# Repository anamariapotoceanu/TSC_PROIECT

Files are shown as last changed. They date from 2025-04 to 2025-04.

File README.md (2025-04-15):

# OpenBook E-Reader

OpenBook este un e-reader open-source construit in jurul microcontrollerului ESP32-C6-WROOM-1. Dispozitivul ofera o experienta de lectura cu afisaj e-paper, butoane fizice, conectivitate wireless si senzori de mediu integrati.

## DIAGRAMA BLOC
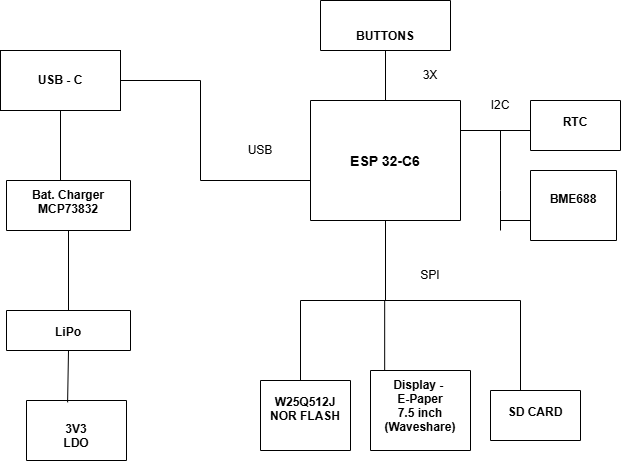
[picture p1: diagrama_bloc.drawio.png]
Diagrama Bloc


## BOM

| DENUMIRE | SITE ACHIZITIONARE | DATASHEET |
|---|---|---|
| BOOT_BUTON | [LINK](https://www.snapeda.com/parts/EVQP7L01P/Panasonic%20Electronic%20Components/view-part/?welcome=home) | [LINK](https://www.snapeda.com/parts/EVQP7L01P/Panasonic/datasheet/) |
| C1 - C10 | [LINK](https://componentsearchengine.com/part-view/CC0402MRX5R5BB106/YAGEO) | [LINK](https://componentsearchengine.com/Datasheets/2/CC0402MRX5R5BB106.pdf) |
| C1_BAT | [LINK](https://componentsearchengine.com/part-view/CC0402MRX5R5BB106/YAGEO) | [LINK](https://componentsearchengine.com/Datasheets/2/CC0402MRX5R5BB106.pdf) |
| C1_BAT2 | [LINK](https://componentsearchengine.com/part-view/CC0402MRX5R5BB106/YAGEO) | [LINK](https://componentsearchengine.com/Datasheets/2/CC0402MRX5R5BB106.pdf) |
| C2_BAT | [LINK](https://componentsearchengine.com/part-view/CC0402MRX5R5BB106/YAGEO) | [LINK](https://componentsearchengine.com/Datasheets/2/CC0402MRX5R5BB106.pdf) |
| C4_USB | [LINK](https://componentsearchengine.com/part-view/CC0402MRX5R5BB106/YAGEO) | [LINK](https://componentsearchengine.com/Datasheets/2/CC0402MRX5R5BB106.pdf) |
| C5_USB | [LINK](https://componentsearchengine.com/part-view/CC0402MRX5R5BB106/YAGEO) | [LINK](https://componentsearchengine.com/Datasheets/2/CC0402MRX5R5BB106.pdf) |
| C10_SUPERCAR | [LINK](https://industry.panasonic.com/global/en/products/control/switch/light-touch/number/evqpuj02k) | [LINK](https://industry.panasonic.com/global/en/downloads?tab=catalog&small_g_cd=203&part_no=EVQPUJ02K) |
| CHANGE_BUTTON | [LINK](https://www.snapeda.com/parts/EVQP7L01P/Panasonic%20Electronic%20Components/view-part/?welcome=home) | [LINK](https://www.snapeda.com/parts/EVQP7L01P/Panasonic/datasheet/) |
| CHG_LED | [LINK](https://www.snapeda.com/parts/KP-1608SURCK/Kingbright/view-part/?ref=search&t=LED%200603) | [LINK](https://www.snapeda.com/parts/KP-1608SURCK/Kingbright/datasheet/) |
| C_DELAY | [LINK](https://componentsearchengine.com/part-view/CC0402MRX5R5BB106/YAGEO) | [LINK](https://componentsearchengine.com/Datasheets/2/CC0402MRX5R5BB106.pdf) |
| D1 | [LINK](https://www.snapeda.com/parts/USBLC6-2SC6Y/STMicroelectronics/view-part/?ref=eda) | [LINK](https://www.snapeda.com/parts/USBLC6-2SC6Y/STMicroelectronics/view-part/?ref=eda) |
| D2 | [LINK](https://ro.mouser.com/ProductDetail/KYOCERA-AVX/SD0805S020S1R0?qs=jCA%252BPfw4LHbpkAoSnwrdjw%3D%3D) | [LINK](https://ro.mouser.com/datasheet/2/40/schottky-3165252.pdf) |
| D3 | [LINK](https://ro.mouser.com/ProductDetail/KYOCERA-AVX/SD0805S020S1R0?qs=jCA%252BPfw4LHbpkAoSnwrdjw%3D%3D) | [LINK](https://ro.mouser.com/datasheet/2/40/schottky-3165252.pdf) |
| D4 | [LINK](https://ro.mouser.com/ProductDetail/KYOCERA-AVX/SD0805S020S1R0?qs=jCA%252BPfw4LHbpkAoSnwrdjw%3D%3D) | [LINK](https://ro.mouser.com/datasheet/2/40/schottky-3165252.pdf) |
| D5 | [LINK](https://ro.mouser.com/ProductDetail/KYOCERA-AVX/SD0805S020S1R0?qs=jCA%252BPfw4LHbpkAoSnwrdjw%3D%3D) | [LINK](https://ro.mouser.com/datasheet/2/40/schottky-3165252.pdf) |
| D6 | [LINK](https://www.snapeda.com/parts/PGB1010603MR/Littelfuse/view-part/?ref=eda) | [LINK](https://www.snapeda.com/parts/PGB1010603MR/Littelfuse%20Inc./datasheet/) |
| D7 | [LINK](https://ro.mouser.com/ProductDetail/KYOCERA-AVX/SD0805S020S1R0?qs=jCA%252BPfw4LHbpkAoSnwrdjw%3D%3D) | [LINK](https://ro.mouser.com/datasheet/2/40/schottky-3165252.pdf) |
| D8 | [LINK](https://www.snapeda.com/parts/PGB1010603MR/Littelfuse/view-part/?ref=eda) | [LINK](https://www.snapeda.com/parts/PGB1010603MR/Littelfuse%20Inc./datasheet/) |
| D9 | [LINK](https://www.snapeda.com/parts/PGB1010603MR/Littelfuse/view-part/?ref=eda) | [LINK](https://www.snapeda.com/parts/PGB1010603MR/Littelfuse%20Inc./datasheet/) |
| D10 | [LINK](https://www.snapeda.com/parts/PGB1010603MR/Littelfuse/view-part/?ref=eda) | [LINK](https://www.snapeda.com/parts/PGB1010603MR/Littelfuse%20Inc./datasheet/) |
| D11 | [LINK](https://www.snapeda.com/parts/PGB1010603MR/Littelfuse/view-part/?ref=eda) | [LINK](https://www.snapeda.com/parts/PGB1010603MR/Littelfuse%20Inc./datasheet/) |
| D12 | [LINK](https://www.snapeda.com/parts/PGB1010603MR/Littelfuse/view-part/?ref=eda) | [LINK](https://www.snapeda.com/parts/PGB1010603MR/Littelfuse%20Inc./datasheet/) |
| EPD_C1 - EPD_C12 | [LINK](https://componentsearchengine.com/part-view/CC0402MRX5R5BB106/YAGEO) | [LINK](https://componentsearchengine.com/Datasheets/2/CC0402MRX5R5BB106.pdf) |
| IC1 | [LINK](https://componentsearchengine.com/part-view/BD5229G-TR/ROHM%20Semiconductor) | [LINK](https://datasheet.datasheetarchive.com/originals/distributors/Datasheets_SAMA/f2b9741ef86007909f138d561a359946.pdf) |
| IC4 | [LINK](https://componentsearchengine.com/part-view/XC6220A331MR-G/Torex) | [LINK](https://product.torexsemi.com/system/files/series/xc6220.pdf) |
| J1 | [LINK](https://componentsearchengine.com/part-view/FH34SRJ-24S-0.5SH(99)/Hirose) | [LINK](https://www.hirose.com/en/product/document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) |
| J2 | [LINK](https://componentsearchengine.com/part-view/USB4110-GF-A/GCT%20(GLOBAL%20CONNECTOR%20TECHNOLOGY)) | [LINK](https://gct.co/files/drawings/usb4110.pdf) |
| J3 | [LINK](https://www.snapeda.com/parts/PRT-14417/SparkFun/view-part/) | [LINK](https://www.snapeda.com/parts/PRT-14417/SparkFun%20Electronics/datasheet/) |
| J4 | [LINK](https://www.snapeda.com/parts/112A-TAAR-R03/Attend/view-part/) | [LINK](https://www.snapeda.com/parts/112A-TAAR-R03/Attend/datasheet/) |
| MCP73831 | [LINK](https://ro.mouser.com/ProductDetail/Microchip-Technology/MCP73831T-2ACI-OT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) | [LINK](https://ro.mouser.com/datasheet/2/268/MCP73831_Family_Data_Sheet_DS20001984H-3441711.pdf) |
| L1 | [LINK](https://ro.mouser.com/ProductDetail/Wurth-Elektronik/744043680?qs=PGXP4M47uW6VkZq%252BkzjrHA%3D%3D) | [LINK](https://www.we-online.com/components/products/datasheet/744043680.pdf) |
| PFMF.050.1 | [LINK](https://ro.mouser.com/ProductDetail/EPCOS-TDK/B72520T0350K062?qs=dEfas%2FXlABIszF52uu7vrg%3D%3D) | [LINK](https://www.tdk-electronics.tdk.com/inf/75/db/CTVS_14/Surge_protection_series.pdf) |
| Q1 | [LINK](https://componentsearchengine.com/part-view/DMG2305UX-7/Diodes%20Incorporated) | [LINK](https://www.diodes.com//assets/Datasheets/DMG2305UX.pdf) |
| Q2 | [LINK](https://componentsearchengine.com/part-view/DMG2305UX-7/Diodes%20Incorporated) | [LINK](https://www.diodes.com//assets/Datasheets/DMG2305UX.pdf) |
| Q3 | [LINK](https://componentsearchengine.com/part-view/SI1308EDL-T1-GE3/Vishay) | [LINK](https://componentsearchengine.com/part-view/SI1308EDL-T1-GE3/Vishay) |
| R1 - R10 | [LINK](https://componentsearchengine.com/part-view/R0402%201%25%20100%20K%20(RC0402FR-07100KL)/YAGEO) | [LINK](https://www.yageo.com/upload/media/product/products/datasheet/rchip/PYu-RC_Group_51_RoHS_L_12.pdf) |
| R1_PINH | [LINK](https://componentsearchengine.com/part-view/R0402%201%25%20100%20K%20(RC0402FR-07100KL)/YAGEO) | [LINK](https://www.yageo.com/upload/media/product/products/datasheet/rchip/PYu-RC_Group_51_RoHS_L_12.pdf) |
| R1_PINH1 | [LINK](https://componentsearchengine.com/part-view/R0402%201%25%20100%20K%20(RC0402FR-07100KL)/YAGEO) | [LINK](https://www.yageo.com/upload/media/product/products/datasheet/rchip/PYu-RC_Group_51_RoHS_L_12.pdf) |
| R1_BAT | [LINK](https://componentsearchengine.com/part-view/R0402%201%25%20100%20K%20(RC0402FR-07100KL)/YAGEO) | [LINK](https://www.yageo.com/upload/media/product/products/datasheet/rchip/PYu-RC_Group_51_RoHS_L_12.pdf) |
| R1_PWRUSB | [LINK](https://componentsearchengine.com/part-view/R0402%201%25%20100%20K%20(RC0402FR-07100KL)/YAGEO) | [LINK](https://www.yageo.com/upload/media/product/products/datasheet/rchip/PYu-RC_Group_51_RoHS_L_12.pdf) |
| R2_PINH | [LINK](https://componentsearchengine.com/part-view/R0402%201%25%20100%20K%20(RC0402FR-07100KL)/YAGEO) | [LINK](https://www.yageo.com/upload/media/product/products/datasheet/rchip/PYu-RC_Group_51_RoHS_L_12.pdf) |
| R2-PINH1 | [LINK](https://componentsearchengine.com/part-view/R0402%201%25%20100%20K%20(RC0402FR-07100KL)/YAGEO) | [LINK](https://www.yageo.com/upload/media/product/products/datasheet/rchip/PYu-RC_Group_51_RoHS_L_12.pdf) |
| R2_USB | [LINK](https://componentsearchengine.com/part-view/R0402%201%25%20100%20K%20(RC0402FR-07100KL)/YAGEO) | [LINK](https://www.yageo.com/upload/media/product/products/datasheet/rchip/PYu-RC_Group_51_RoHS_L_12.pdf) |
| R2_USB1 | [LINK](https://componentsearchengine.com/part-view/R0402%201%25%20100%20K%20(RC0402FR-07100KL)/YAGEO) | [LINK](https://www.yageo.com/upload/media/product/products/datasheet/rchip/PYu-RC_Group_51_RoHS_L_12.pdf) |
| RESET_BUTTON | [LINK](https://www.snapeda.com/parts/EVQP7L01P/Panasonic%20Electronic%20Components/view-part/?welcome=home) | [LINK](https://www.snapeda.com/parts/EVQP7L01P/Panasonic/datasheet/) |
| R_BOOT | [LINK](https://componentsearchengine.com/part-view/R0402%201%25%20100%20K%20(RC0402FR-07100KL)/YAGEO) | [LINK](https://www.yageo.com/upload/media/product/products/datasheet/rchip/PYu-RC_Group_51_RoHS_L_12.pdf) |
| R_CAPACITOR | [LINK](https://componentsearchengine.com/part-view/R0402%201%25%20100%20K%20(RC0402FR-07100KL)/YAGEO) | [LINK](https://www.yageo.com/upload/media/product/products/datasheet/rchip/PYu-RC_Group_51_RoHS_L_12.pdf) |
| R_CHANGE | [LINK](https://componentsearchengine.com/part-view/R0402%201%25%20100%20K%20(RC0402FR-07100KL)/YAGEO) | [LINK](https://www.yageo.com/upload/media/product/products/datasheet/rchip/PYu-RC_Group_51_RoHS_L_12.pdf) |
| R_CL1 | [LINK](https://componentsearchengine.com/part-view/R0402%201%25%20100%20K%20(RC0402FR-07100KL)/YAGEO) | [LINK](https://www.yageo.com/upload/media/product/products/datasheet/rchip/PYu-RC_Group_51_RoHS_L_12.pdf) |
| R_RESET | [LINK](https://componentsearchengine.com/part-view/R0402%201%25%20100%20K%20(RC0402FR-07100KL)/YAGEO) | [LINK](https://www.yageo.com/upload/media/product/products/datasheet/rchip/PYu-RC_Group_51_RoHS_L_12.pdf) |
| SENSOR2 | [LINK](https://www.snapeda.com/parts/BME680/Bosch/view-part/?welcome=home) | [LINK](https://www.snapeda.com/parts/BME680/Bosch%20Sensortec/datasheet/) |
| TP | [nan](nan) | [nan](nan) |
| U1 | [LINK](https://www.snapeda.com/parts/W25Q512JVEIQ/Winbond+Electronics/view-part/?ref=eda) | [LINK](https://www.snapeda.com/parts/W25Q512JVEIQ/Winbond+Electronics/view-part/?ref=eda) |
| U2 | [LINK](https://www.snapeda.com/parts/ESP32-C6-WROOM-1-N8/Espressif+Systems/view-part/?ref=eda) | [LINK](https://www.snapeda.com/parts/ESP32-C6-WROOM-1-N8/Espressif%20Systems/datasheet/) |
| U3 | [LINK](https://www.snapeda.com/parts/DS3231SN%23/Analog+Devices/view-part/?ref=eda) | [LINK](https://www.snapeda.com/parts/DS3231SN%23/Analog%20Devices/datasheet/) |
| U4 | [LINK](https://www.snapeda.com/parts/MAX17048G+T10/Analog+Devices/view-part/?ref=eda) | [LINK ](https://www.snapeda.com/parts/MAX17048G+T10/Analog%20Devices/datasheet/) |

## Functionalitate hardware detaliata

OpenBook este un e-reader open-source construit in jurul microcontrollerului ESP32-C6-WROOM-1-N8. Sistemul este modular si a fost gandit pentru consum redus de energie, simplitate si extensibilitate.

### Microcontroller - ESP32-C6-WROOM-1-N8
- Procesor RISC-V 32-bit, frecventa 160 MHz+
- Suport pentru Wi-Fi 6, BLE 5 si USB 2.0 FS
- Interfete disponibile: SPI, I2C, UART, GPIO
- Consum redus: aproximativ 60 mA in activ, sub 100 uA in deep sleep

### Display - E-Paper 7.5 inch (Waveshare)
- Rezolutie 800x480 alb-negru
- Interfata SPI, partajata cu alte periferice
- Foloseste linii dedicate pentru ceas, date, comenzi, reset si status
- Consum doar in timpul refreshului (~30 - 50 mA)

### Senzori de mediu
- **BME688** masoara temperatura, umiditatea, presiunea si calitatea aerului
- Conectat pe magistrala I2C, alaturi de RTC si fuel gauge
- **DS3231**  este un RTC cu backup pe supercapacitor si semnal de intrerupere catre microcontroller
- **MAX17048** (fuel gauge): I2C + ALERT pe IO16
- Un fuel gauge care poate trimite alerta in caz de nivel scazut

### Memorie externa
- W25Q512J, o memorie NOR Flash de 64MB, conectata prin SPI
- Are chip select dedicat pentru acces independent de afisaj

### SD Card (optional)
- Suportat pe aceeasi magistrala SPI cu chip select separat
- Permite extinderea capacitatii de stocare

### Butoane
- Trei butoane tactile conectate direct la pinii microcontrollerului
- Sunt folosite pentru navigare si selectie in interfata
- Gestionate prin intreruperi, cu debounce hardware si software

### Alimentare
- Sistemul este alimentat de o baterie Li-Po de 2500 mAh
- Incarcarea se face prin USB-C cu ajutorul unui MCP73831
- Un semnal digital permite monitorizarea starii de incarcare
- Tensiunea este stabilizata la 3.3V printr-un LDO

### USB-C
- Asigura incarcare si transfer de fisiere in mod MSC (Mass Storage)
- Liniile USB sunt protejate cu diode ESD

### Consum estimativ
- In activ cu Wi-Fi: intre 60 si 100 mA
- In activ fara Wi-Fi: intre 40 si 60 mA
- In standby: aproximativ 10 mA
- In deep sleep: sub 100 uA

### PCB si carcasa
- Placa in 2 straturi, rutare clara pentru alimentare si SPI
- Separare intre zonele digitale si analogice
- Carcasa ABS/PC, usoara si ergonomica

| IO Pin | Semnal | Rol |
|---|---|---|
| EN | RESET  | Semnal de intrare pentru resetare |
| 0| INT_RTC | Semnal de intrerupere generat de modulul RTC |
| 1 | 32KHZ | Oscilator 32kHz pentru RTC |
| 2 | MISO | SPI MISO date de la periferice |
| 3 | EPD_BUSY | Semnal ocupat de la afisaj e-paper |
| 4 | SS_SD | Chip Select pentru SD Card |
| 5 | EPD_DC | Comanda date/controle pentru e-paper |
| 6 | SCK | SPI Clock comun pentru SD, flash si e-paper |
| 7 | MOSI | SPI MOSI date catre SD, flash, e-paper |
| 8 | GPIO8 | Selectarea cardului SD |
| 9 | IO/BOOT | Mod de boot selectabil |
| 10 | EPD_CS | Chip Select pentru afisaj e-paper |
| 11 | FLASH_CS | Chip Select pentru flash NOR |
| 12 | USB_D- | Linie pozitiva pentru USB Full-Speed |
| 13 | USB_D+ | Linie pozitiva pentru USB Full-Speed |
| 14 | NEUTILIZAT | NEUTILIZAT |
| 15 | IO/CHANGE | Detectarea modificarii starii |
| 16 | TX | Debug |
| 17 | RX | Debug |
| 18 | RTC_RST | Reset pentru modulul RTC|
| 19 | I2C_PW | Gestionarea alimentarii pentru dispozitivele I2C |
| 20 | EPD_3V3_C | Gestionarea alimentarii display-ului |
| 21 | SDA | I2C SDA conexiune alternativa RTC |
| 22 | SCL | I2C SCL conexiune alternativa RTC |
| 23 | EPD_RST | Reset alternativ e-paper display |

## Erori

Am aprobat erorile din schematic deoarece alimentarile sunt corecte din punct de vedere hardware.

Am aprobat erorile de DRC aparute la mufa USB din cauza celor doua gauri, deoarece acestea sunt conforme cu specificatiile
mecanice ale mufei si nu afecteaza functionalitatea.

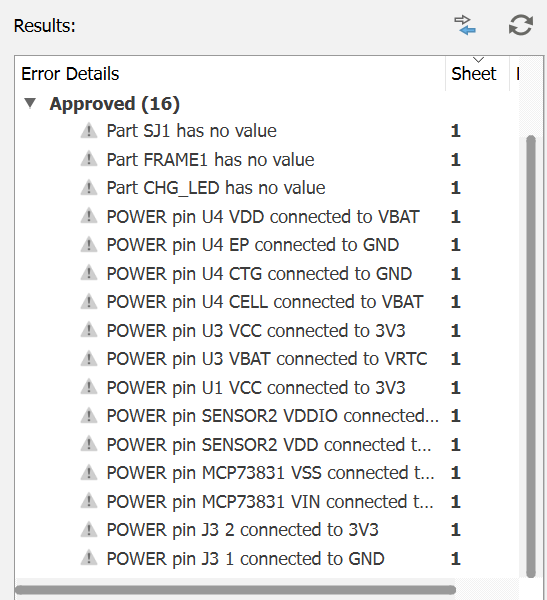
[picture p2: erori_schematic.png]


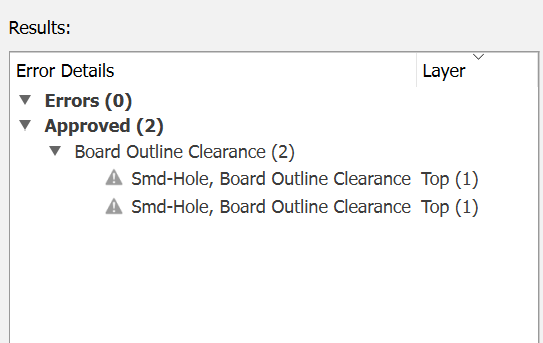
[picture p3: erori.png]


## Imagini
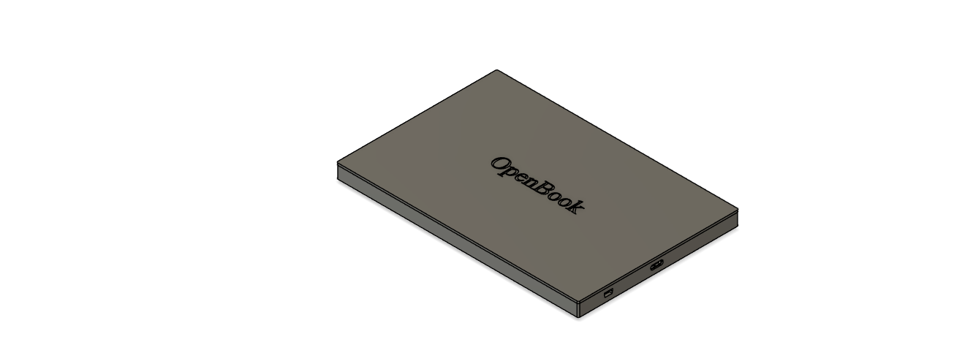
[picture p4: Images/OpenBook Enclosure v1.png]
OpenBook

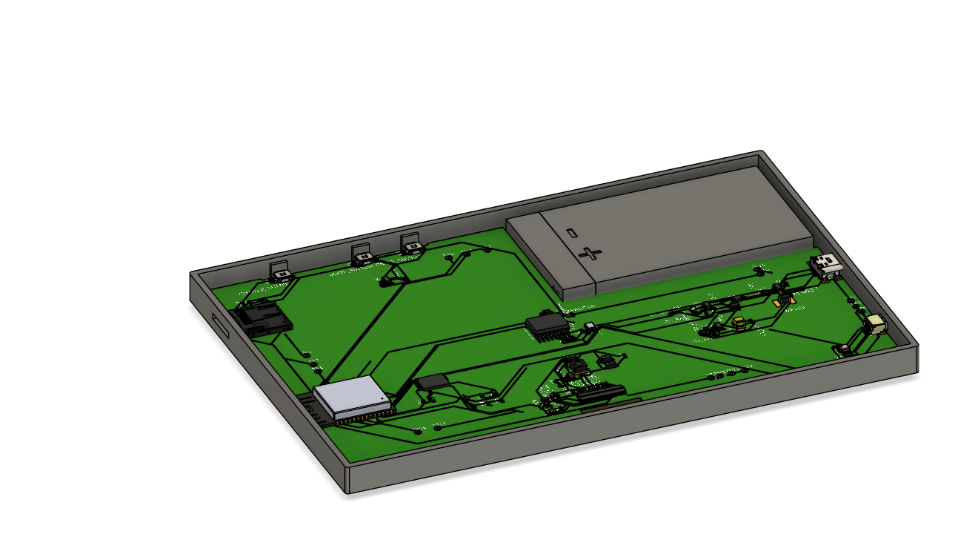
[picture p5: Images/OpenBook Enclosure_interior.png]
OpenBook

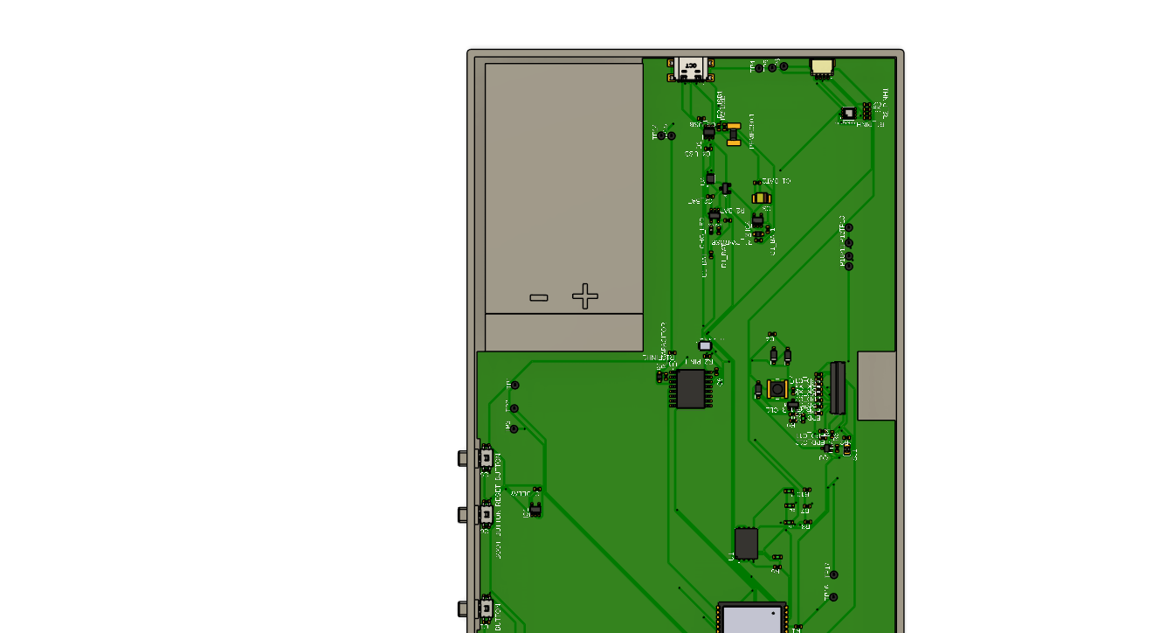
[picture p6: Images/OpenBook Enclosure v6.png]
OpenBook

OpenBook
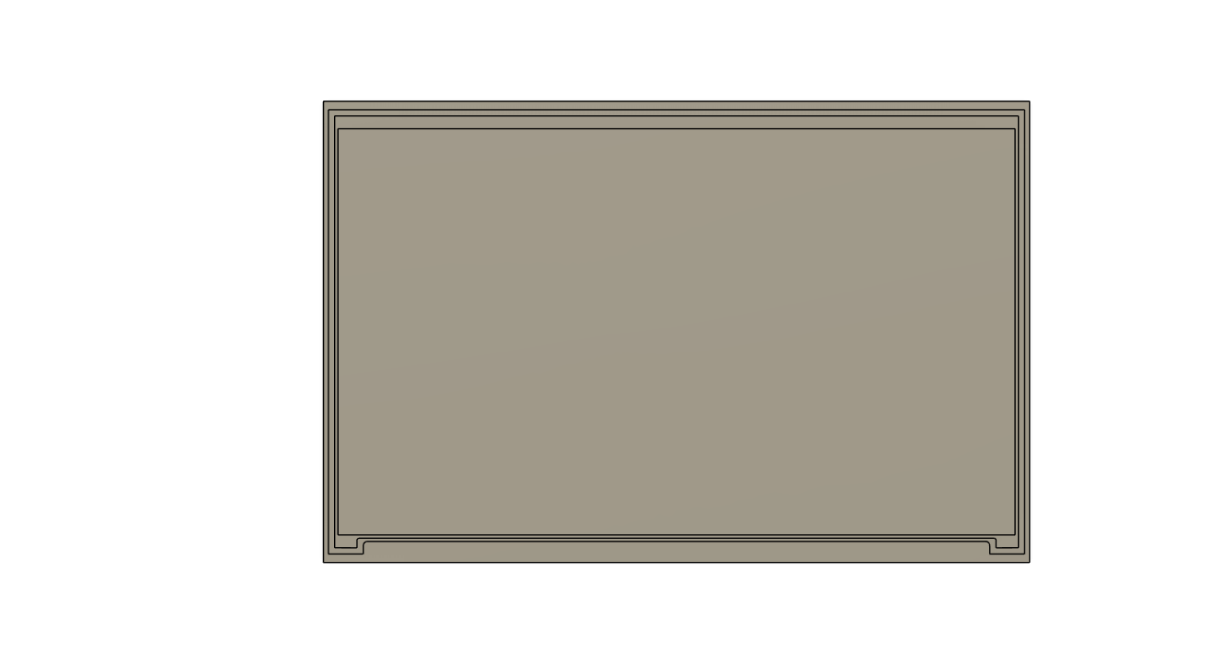
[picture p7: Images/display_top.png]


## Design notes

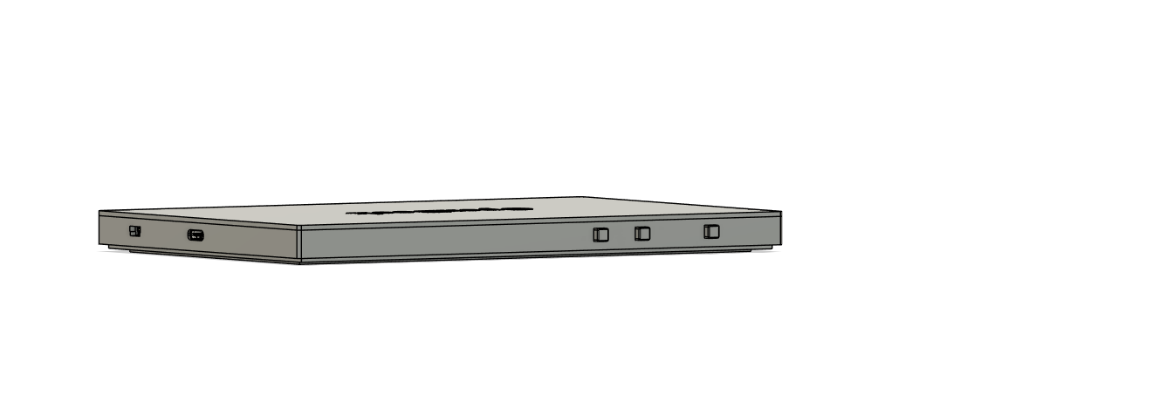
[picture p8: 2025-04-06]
Images/OpenBook Enclosure v3.png

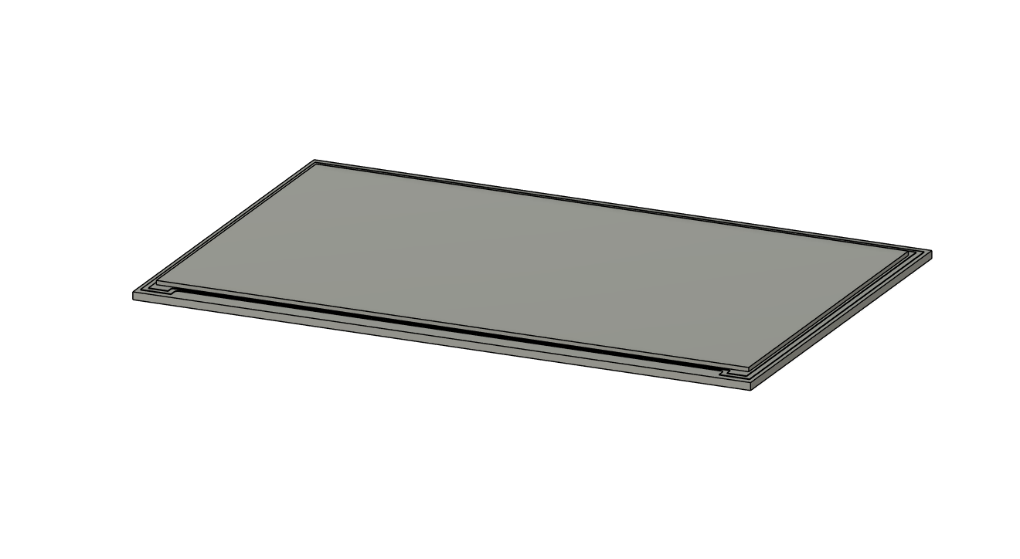
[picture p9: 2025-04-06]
Images/display_v1.png

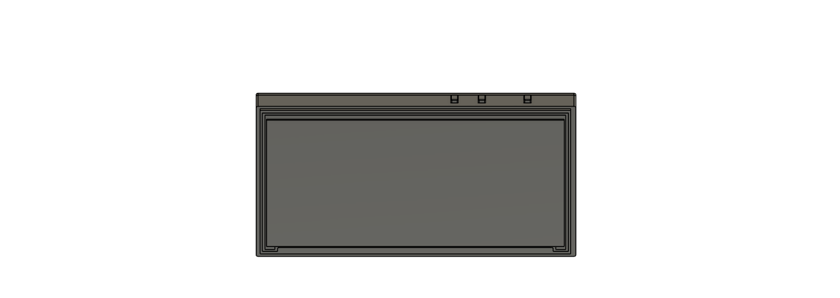
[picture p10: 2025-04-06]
Images/OpenBook Enclosure v4.png

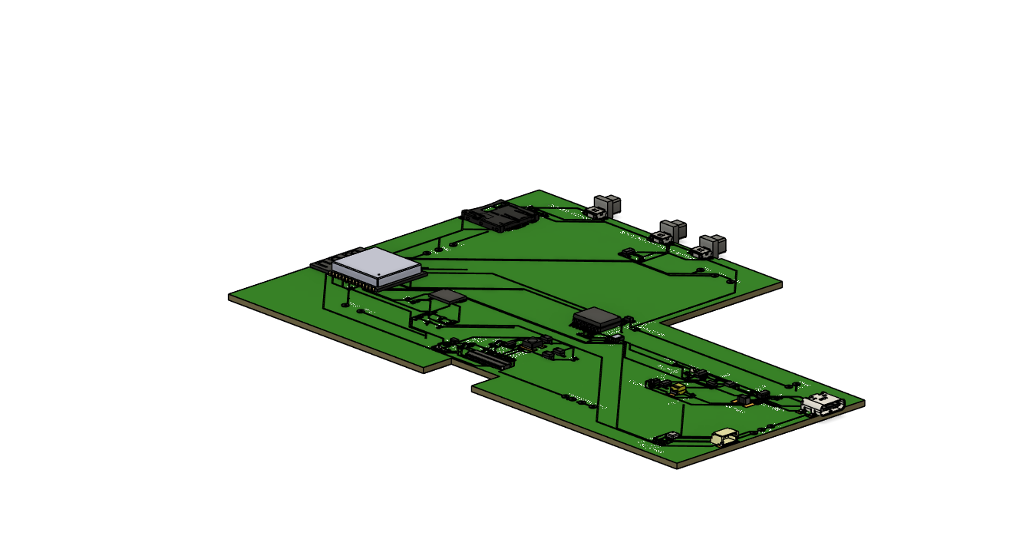
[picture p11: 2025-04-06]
Images/pcb.png

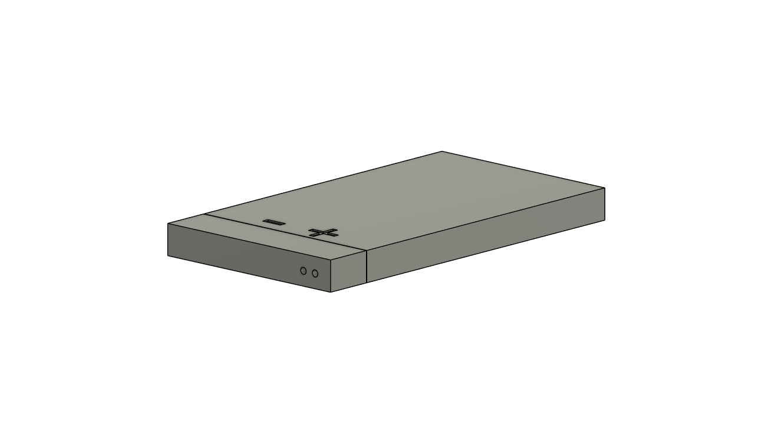
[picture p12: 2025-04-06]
Images/baterie.png

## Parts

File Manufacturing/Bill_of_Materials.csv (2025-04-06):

Qty | Value | Device | Package | Parts | Description | ARROW_PART_NUMBER | ARROW_PRICE-STOCK | AVAILABILITY | CENTROID_NOT_SPECIFIED | CHECK_PRICES | COPYRIGHT | DATASHEET | DESCRIPTION | DIGIKEY_DESCRIPTION | DIGIKEY_PART_NUMBER | HEIGHT | LEAD_FREE | MANUFACTURER_NAME | MANUFACTURER_PART_NUMBER | MF | MFR_NAME | MOUSER_PART_NUMBER | MOUSER_PRICE-STOCK | MOUSER_TESTING_PART_NUMBER | MOUSER_TESTING_PRICE-STOCK | MP | MPN | PACKAGE | POPULARITY | PREFIX | PRICE | PROD_ID | PURCHASE-URL | ROHS | SNAPEDA_LINK | SPICEMODEL | SPICEPREFIX | TEMPERATURE_RANGE_HIGH | TEMPERATURE_RANGE_LOW | TP_SIGNAL_NAME | VALUE
1 |  | ADAFRUIT_LEDCHIP-LED0603 | ADAFRUIT_CHIP-LED0603 | CHG_LED | LED
1 |  | SJ | SJ | SJ1 | SMD solder JUMPER |  |  |  |  |  |  |  |  |  |  |  |  |  |  |  |  |  |  |  |  |  |  |  | 3
1 | 0.1uF/50V | ESP32_WROVER_EAGLE-LTSPICE_CC0402 | ESP32_WROVER_EAGLE-LTSPICE_C0402 | EPD_C5 | CAPACITOR, European symbol |  |  |  |  |  |  |  |  |  |  |  |  |  |  |  |  |  |  |  |  |  |  |  |  |  |  |  |  |  |  | NONE | C
1 | 0.47 | ESP32_WROVER_EAGLE-LTSPICE_RR0402 | ESP32_WROVER_EAGLE-LTSPICE_R0402 | R3 | RESISTOR, European symbol |  |  |  |  |  |  |  |  |  |  |  |  |  |  |  |  |  |  |  |  |  |  |  |  |  |  |  |  |  |  | NONE | R
1 | 100K | ESP32_WROVER_EAGLE-LTSPICE_RR0402 | ESP32_WROVER_EAGLE-LTSPICE_R0402 | R1_PWRUSB | RESISTOR, European symbol |  |  |  |  |  |  |  |  |  |  |  |  |  |  |  |  |  |  |  |  |  |  |  |  |  |  |  |  |  |  | NONE | R
4 | 100nF | EAGLE-LTSPICE_CC0402 | ESP32_WROVER_EAGLE-LTSPICE_C0402 | C6, C9, C10, C_DELAY | CAPACITOR, European symbol |  |  |  |  |  |  |  |  |  |  |  |  |  |  |  |  |  |  |  |  |  |  |  |  |  |  |  |  |  |  | NONE | C
4 | 100nF | ESP32_WROVER_EAGLE-LTSPICE_CC0402 | ESP32_WROVER_EAGLE-LTSPICE_C0402 | C1, C2, C4_USB, C8 | CAPACITOR, European symbol |  |  |  |  |  |  |  |  |  |  |  |  |  |  |  |  |  |  |  |  |  |  |  |  |  |  |  |  |  |  | NONE | C
1 | 100uF TANT | RCL_CPOL-EUCT3528 | RCL_CT3528 | C3 | POLARIZED CAPACITOR, European symbol |  |  |  |  |  |  |  |  |  |  |  |  |  |  |  |  |  |  |  |  |  |  |  | 0 |  |  |  |  |  |  |  | C
16 | 10K | ESP32_WROVER_EAGLE-LTSPICE_RR0402 | ESP32_WROVER_EAGLE-LTSPICE_R0402 | R1, R1_PINH, R1_PINH1, R2_PINH, R2_PINH1, R4, R5, R6, R7, R8, R9, R10, R_BOOT, R_CHANGE, R_CL1, R_RESET | RESISTOR, European symbol |  |  |  |  |  |  |  |  |  |  |  |  |  |  |  |  |  |  |  |  |  |  |  |  |  |  |  |  |  |  | NONE | R
1 | 10uF | ESP32_WROVER_EAGLE-LTSPICE_CC0402 | ESP32_WROVER_EAGLE-LTSPICE_C0402 | C7 | CAPACITOR, European symbol |  |  |  |  |  |  |  |  |  |  |  |  |  |  |  |  |  |  |  |  |  |  |  |  |  |  |  |  |  |  | NONE | C
1 | 112A-TAAR-R03_ATTEND | 112A-TAAR-R03_ATTEND | 112ATAARR03ATTEND | J4 | Micro SD Card Socket, Push-Push Type, Top Mount, SMT, H=1.83mm, 10u |  |  |  |  |  |  |  | Micro SD Card Socket | Push-Push Type | Top Mount | SMT | H=1.83mm | 10u |  |  | 1.9mm |  | ATTEND | 112A-TAAR-R03 ATTEND
1 | 15 | ESP32_WROVER_EAGLE-LTSPICE_RR0402 | ESP32_WROVER_EAGLE-LTSPICE_R0402 | R_CAPACITOR | RESISTOR, European symbol |  |  |  |  |  |  |  |  |  |  |  |  |  |  |  |  |  |  |  |  |  |  |  |  |  |  |  |  |  |  | NONE | R
1 | 1uF | EAGLE-LTSPICE_CC0402 | ESP32_WROVER_EAGLE-LTSPICE_C0402 | C5 | CAPACITOR, European symbol |  |  |  |  |  |  |  |  |  |  |  |  |  |  |  |  |  |  |  |  |  |  |  |  |  |  |  |  |  |  | NONE | C
2 | 1uF/50V | EAGLE-LTSPICE_CC0402 | ESP32_WROVER_EAGLE-LTSPICE_C0402 | EPD_C1, EPD_C2 | CAPACITOR, European symbol |  |  |  |  |  |  |  |  |  |  |  |  |  |  |  |  |  |  |  |  |  |  |  |  |  |  |  |  |  |  | NONE | C
7 | 1uF/50V | ESP32_WROVER_EAGLE-LTSPICE_CC0402 | ESP32_WROVER_EAGLE-LTSPICE_C0402 | EPD_C6, EPD_C7, EPD_C8, EPD_C9, EPD_C10, EPD_C11, EPD_C12 | CAPACITOR, European symbol |  |  |  |  |  |  |  |  |  |  |  |  |  |  |  |  |  |  |  |  |  |  |  |  |  |  |  |  |  |  | NONE | C
1 | 2.2 | ESP32_WROVER_EAGLE-LTSPICE_RR0402 | ESP32_WROVER_EAGLE-LTSPICE_R0402 | R2 | RESISTOR, European symbol |  |  |  |  |  |  |  |  |  |  |  |  |  |  |  |  |  |  |  |  |  |  |  |  |  |  |  |  |  |  | NONE | R
1 | 200 | ESP32_WROVER_EAGLE-LTSPICE_RR0402 | ESP32_WROVER_EAGLE-LTSPICE_R0402 | R1_BAT | RESISTOR, European symbol |  |  |  |  |  |  |  |  |  |  |  |  |  |  |  |  |  |  |  |  |  |  |  |  |  |  |  |  |  |  | NONE | R
2 | 20V/4.2A/52mO/1.4W | ESP32_WROVER_SPARKFUN-DISCRETESEMI_MOSFET_PCH-DMG2305UX-7 | ESP32_WROVER_SPARKFUN-DISCRETESEMI_SOT23-3 | Q1, Q2 | P-channel MOSFETs |  |  |  |  |  |  |  |  |  |  |  |  |  |  |  |  |  |  |  |  |  |  |  |  |  |  | TRAN-14388 |  |  |  |  |  |  |  |  | 20V/4.2A/52mO/1.4W
1 | 2K | ESP32_WROVER_EAGLE-LTSPICE_RR0402 | ESP32_WROVER_EAGLE-LTSPICE_R0402 | R2_BAT | RESISTOR, European symbol |  |  |  |  |  |  |  |  |  |  |  |  |  |  |  |  |  |  |  |  |  |  |  |  |  |  |  |  |  |  | NONE | R
3 | 4.7uF | EAGLE-LTSPICE_CC0402 | ESP32_WROVER_EAGLE-LTSPICE_C0402 | C1_BAT, C1_BAT1, C2_BAT | CAPACITOR, European symbol |  |  |  |  |  |  |  |  |  |  |  |  |  |  |  |  |  |  |  |  |  |  |  |  |  |  |  |  |  |  | NONE | C
2 | 4.7uF | ESP32_WROVER_EAGLE-LTSPICE_CC0402 | ESP32_WROVER_EAGLE-LTSPICE_C0402 | C1_BAT2, C5_USB | CAPACITOR, European symbol |  |  |  |  |  |  |  |  |  |  |  |  |  |  |  |  |  |  |  |  |  |  |  |  |  |  |  |  |  |  | NONE | C
1 | 4.7uF/25V | ESP32_WROVER_EAGLE-LTSPICE_CC0402 | ESP32_WROVER_EAGLE-LTSPICE_C0402 | C4 | CAPACITOR, European symbol |  |  |  |  |  |  |  |  |  |  |  |  |  |  |  |  |  |  |  |  |  |  |  |  |  |  |  |  |  |  | NONE | C
2 | 5k1 | ESP32_WROVER_EAGLE-LTSPICE_RR0402 | ESP32_WROVER_EAGLE-LTSPICE_R0402 | R2-USB, R2-USB1 | RESISTOR, European symbol |  |  |  |  |  |  |  |  |  |  |  |  |  |  |  |  |  |  |  |  |  |  |  |  |  |  |  |  |  |  | NONE | R
1 | 68uH | 744043680IND_4828-WE-TPC_WRE | IND_4828-WE-TPC_WRE | L1 |  |  |  |  |  |  | Copyright (C) 2024 Ultra Librarian. All rights reserved. |  |  |  |  |  |  |  | 744043680 |  | Wurth Electronics
1 | BD5229G-TR | BD5229G-TR | SOT95P280X125-5N | IC1 | Voltage Detector with Adjustable Delay Time: CMOS processes are utilized to develop high precision, low current consumption CMOS reset ICs that allow arbitrary setting of the delay time. The extensive lineup includes both Nch Open Drain and CMOS output types in a wide range of detection voltages (from 2.3V to 6.0V, in 0.1V steps), enabling selection of the ideal solution based on customer requirements. In addition, the entire series is of course both lead-free and RoHS-compliant. |  |  |  |  |  |  |  | Voltage Detector with Adjustable Delay Time: CMOS processes are utilized to develop high precision | low current consumption CMOS reset ICs that allow arbitrary setting of the delay time. The extensive lineup includes both Nch Open Drain and CMOS output types in a wide range of detection voltages (from 2.3V to 6.0V | in 0.1V steps) | enabling selection of the ideal solution based on customer requirements. In addition | the entire series is of course both lead-free and RoHS-compliant. |  |  | 1.25mm |  | ROHM Semiconductor | BD5229G-TR |  |  | 755-BD5229G-TR | https://www.mouser.co.uk/ProductDetail/ROHM-Semiconductor/BD5229G-TR?qs=4kLU8WoGk0vvnhrrYwdszw%3D%3D
3 | BUTTON_CUSYOMV1 | BUTTON_CUSYOMV1 | MYBUTTON | BOOT_BUTTON, CHANGE_BUTTON, RESET_BUTTON
1 | CPH3225A | CPH3225A | CAPCP3225X100N | C10_SUPERCAP | Cap 0.011F 3.3V 1210 Flat Check availability |  |  | Not in stock |  | https://www.snapeda.com/parts/CPH3225A/Seiko+Instruments/view-part/?ref=eda |  |  | 11 mF (EDLC) Supercapacitor 3.3 V 1210 (3225 Metric) - - |  |  |  |  |  |  | Seiko Instruments |  |  |  |  |  | CPH3225A |  | 1210 Seiko |  |  | None |  | https://www.snapeda.com/api/url_track_click_mouser/?unipart_id=562593&manufacturer=Seiko Instruments&part_name=CPH3225A&search_term=None |  | https://www.snapeda.com/parts/CPH3225A/Seiko+Instruments/view-part/?ref=snap
1 | DS3231SN# | DS3231SN# | SOIC127P1032X265-16N | U3 | Real Time Clock Serial 16-Pin SOIC W T/R Check availability |  |  | In Stock |  | https://www.snapeda.com/parts/DS3231SN%23/Analog+Devices/view-part/?ref=eda |  |  | Extremely Accurate I²C-Integrated RTC/TCXO/Crystal |  |  |  |  |  |  | Analog Devices |  |  |  |  |  | DS3231SN# |  | SOIC-16 Maxim |  |  | None |  | https://www.snapeda.com/api/url_track_click_mouser/?unipart_id=99048&manufacturer=Analog Devices&part_name=DS3231SN#&search_term=None |  | https://www.snapeda.com/parts/DS3231SN%23/Analog+Devices/view-part/?ref=snap
1 | ESP32-C6-WROOM-1-N8 | ESP32-C6-WROOM-1-N8 | XCVR_ESP32-C6-WROOM-1-N8 | U2 | Check availability |  |  | In Stock |  | https://www.snapeda.com/parts/ESP32-C6-WROOM-1-N8/Espressif+Systems/view-part/?ref=eda |  |  | Multiprotocol Modules ESP32-C6 module | Wi-Fi 6 in 2.4 GHz band | Bluetooth 5 | Zigbee 3.0 and Thread. ESP34-WROOM Compatible - ENGINEERING SAMPLE |  |  |  |  |  |  | Espressif Systems |  |  |  |  |  | ESP32-C6-WROOM-1-N8 |  | None |  |  | None |  |  |  | https://www.snapeda.com/parts/ESP32-C6-WROOM-1-N8/Espressif+Systems/view-part/?ref=snap
1 | ESP32C6_VARISTORCN1812 | ESP32C6_VARISTORCN1812 | ESP32C6_VARISTOR_CT/CN1812 | PFMF.050.1 | VARISTOR |  |  |  |  |  |  |  |  |  |  |  |  |  |  |  |  |  |  |  |  |  |  |  | 0
2 | ESP32_WROVER_AVX---SD0805S020S1R0_AVX_SD0805S020S1R0_0_0AVX_SD0805S020S1R0_0_0 | ESP32_WROVER_AVX---SD0805S020S1R0_AVX_SD0805S020S1R0_0_0AVX_SD0805S020S1R0_0_0 | ESP32_WROVER_AVX---SD0805S020S1R0_AVX_SD0805S020S1R0_0 | D2, D7 | Schottky Barrier Rectifier Diode |  |  |  | No |  |  | http://datasheets.avx.com/schottky.pdf |  | DIODE SCHOTTKY 20V 1A 0805 | 478-7800-1-ND |  | yes |  |  | AVX |  | 581-SD0805S020S1R0 |  |  |  |  |  | 0805 (2012 metric) |  | D |  |  |  | yes |  |  |  | +125°C | -55°C
1 | ESP32_WROVER_BME680_BME680 | ESP32_WROVER_BME680_BME680 | ESP32_WROVER_BME680_PSON80P300X300X100-8N | SENSOR2 | Integrated Environmental Unit |  |  | Unavailable |  |  |  |  | Integrated Environmental Unit |  |  |  |  |  |  | Bosch Sensortec |  |  |  |  |  | BME680 |  | LGA-8 Bosch Tools |  |  | None
1 | ESP32_WROVER_SPARKFUN-IC-POWER_MCP73831 | ESP32_WROVER_SPARKFUN-IC-POWER_MCP73831 | ESP32_WROVER_SPARKFUN-IC-POWER_SOT23-5 | MCP73831 | MCP73831T Li-Ion, Li-Pol Controller |  |  |  |  |  |  |  |  |  |  |  |  |  |  |  |  |  |  |  |  |  |  |  |  |  |  | IC-09995
1 | FH34SRJ-24S-0.5SH_99_ | FH34SRJ-24S-0.5SH_99_ | FH34SRJ24S05SH99 | J1 | (0.50mm) Surface Mount, Right Angle |  |  |  |  |  |  |  | 24 Position FFC | FPC Connector Contacts | (0.50mm) Surface Mount | Right Angle |  |  | 1.1mm |  | Hirose | FH34SRJ-24S-0.5SH(99) |  |  | 798-FH34SRJ24S05SH99 | https://www.mouser.co.uk/ProductDetail/Hirose-Connector/FH34SRJ-24S-0.5SH99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
1 | MAX17048G+T10 | MAX17048G+T10 | SON50P200X200X80-9N | U4 | Check availability |  |  | In Stock |  | https://www.snapeda.com/parts/MAX17048G+T10/Analog+Devices/view-part/?ref=eda |  |  | 3µA 1-Cell/2-Cell Fuel Gauge with ModelGauge |  |  |  |  |  |  | Analog Devices |  |  |  |  |  | MAX17048G+T10 |  | TDFN-8 Maxim |  |  | None |  | https://www.snapeda.com/api/url_track_click_mouser/?unipart_id=329239&manufacturer=Analog Devices&part_name=MAX17048G+T10&search_term=None |  | https://www.snapeda.com/parts/MAX17048G+T10/Analog+Devices/view-part/?ref=snap
3 | MBR0530 | MBR0530 | SOD3716X135N | D3\, D4, D5 | ON SEMICONDUCTOR - MBR0530 - DIODE, SCHOTTKY, 0.5A, 30V, SOD-123 |  |  | In Stock |  | https://www.snapeda.com/parts/MBR0530/Onsemi/view-part/?ref=eda |  |  | Diode Schottky 30 V 500mA Surface Mount SOD-123 |  |  |  |  |  |  | ON Semiconductor |  |  |  |  |  | MBR0530 |  | SOD-123-2 ON Semiconductor |  |  | None |  | https://www.snapeda.com/api/url_track_click_mouser/?unipart_id=179458&manufacturer=ON Semiconductor&part_name=MBR0530&search_term=None |  | https://www.snapeda.com/parts/MBR0530/Onsemi/view-part/?ref=snap
6 | PGB1010603MR | PGB1010603MR | DIOC1608X36N | D6, D8, D9, D10, D11, D12 | Check availability |  |  | In Stock |  | https://www.snapeda.com/parts/PGB1010603MR/Littelfuse/view-part/?ref=eda |  |  | 150V (Typ) Clamp - Ipp Tvs Diode Surface Mount 0603 (1608 Metric) |  |  |  |  |  |  | Littelfuse Inc. |  |  |  |  |  | PGB1010603MR |  | 0603 Littelfuse Inc. |  |  | None |  | https://www.snapeda.com/api/url_track_click_mouser/?unipart_id=5659453&manufacturer=Littelfuse Inc.&part_name=PGB1010603MR&search_term=None |  | https://www.snapeda.com/parts/PGB1010603MR/Littelfuse/view-part/?ref=snap
1 | QWIIC_RIGHT_ANGLE | QWIIC_CONNECTORJS-1MM | JST04_1MM_RA | J3 | SparkFun I2C Standard Qwiic Connector |  |  |  |  |  |  |  |  |  |  |  |  |  |  |  |  |  |  |  |  |  |  |  |  |  |  | CONN-13694 |  |  |  |  |  |  |  |  | QWIIC_RIGHT_ANGLE
1 | SAMACSYS_PARTS_USB4110-GF-A | SAMACSYS_PARTS_USB4110-GF-A | SAMACSYS_PARTS_USB4110GFA | J2 | CONN USB 2.0 TYPE-C R/A SMT |  |  |  |  |  |  |  | CONN USB 2.0 TYPE-C R/A SMT |  |  | 3.26mm |  | GCT (GLOBAL CONNECTOR TECHNOLOGY) | USB4110-GF-A |  |  | 640-USB4110-GF-A | https://www.mouser.co.uk/ProductDetail/GCT/USB4110-GF-A?qs=KUoIvG%2F9IlYiZvIXQjyJeA%3D%3D
1 | SI1308EDL-T1-GE3 | SI1308EDL-T1-GE3 | SOT65P210X110-3N | Q3 | MOSFET N-Ch 30V 1.5A TrenchFET SC70 Vishay Si1308EDL-T1-GE3 N-channel MOSFET Transistor, 1.5 A, 30 V, 3-Pin SC-70 |  |  | In Stock |  | https://www.snapeda.com/parts/SI1308EDL-T1-GE3/Vishay+Siliconix/view-part/?ref=eda |  |  | Si1308EDL-T1-GE3 N-channel MOSFET Transistor | 1.5 A | 30 V | 3-Pin SC-70 | Siliconix / Vishay SI1308EDL-T1-GE3 |  |  |  |  |  |  | Vishay Siliconix |  |  |  |  |  | SI1308EDL-T1-GE3 |  | SOT-323 Vishay Semiconductor |  |  | None |  | https://www.snapeda.com/api/url_track_click_mouser/?unipart_id=274603&manufacturer=Vishay Siliconix&part_name=SI1308EDL-T1-GE3&search_term=None |  | https://www.snapeda.com/parts/SI1308EDL-T1-GE3/Vishay+Siliconix/view-part/?ref=snap
17 | TPTP20R | TPTP20R | TP20R | TP1, TP2, TP3, TP4, TP5, TP6, TP7, TP8, TP9, TP10, TP11, TP12, TP13, TP14, TP15, TP16, TP17 | Test pad |  |  |  |  |  |  |  |  |  |  |  |  |  |  |  |  |  |  |  |  |  |  |  | 2
1 | USBLC6-2SC6Y | USBLC6-2SC6Y | SOT95P280X145-6N | D1 | Low Cap. ESD Protection Auto SOT-23-6 STMicroelectronics USBLC6-2SC6Y, Dual Uni-Directional TVS Diode Array, 6-Pin SOT-23 |  |  | In Stock |  | https://www.snapeda.com/parts/USBLC6-2SC6Y/STMicroelectronics/view-part/?ref=eda |  |  | 17V Clamp 5A (8/20µs) Ipp Tvs Diode Surface Mount SOT-23-6 |  |  |  |  |  |  | STMicroelectronics |  |  |  |  |  | USBLC6-2SC6Y |  | SOT-23-6 STMicroelectronics |  |  | None |  |  |  | https://www.snapeda.com/parts/USBLC6-2SC6Y/STMicroelectronics/view-part/?ref=snap
1 | W25Q512JVEIQ | W25Q512JVEIQ | SON127P600X800X80-9N | U1 | Check availability |  |  | In Stock |  | https://www.snapeda.com/parts/W25Q512JVEIQ/Winbond+Electronics/view-part/?ref=eda |  |  | FLASH - NOR Memory IC 512Mb (64M x 8) SPI - Quad I/O 133 MHz 8-WSON (8x6) |  |  |  |  |  |  | Winbond Electronics |  |  |  |  |  | W25Q512JVEIQ |  | Package |  |  | None |  |  |  | https://www.snapeda.com/parts/W25Q512JVEIQ/Winbond+Electronics/view-part/?ref=snap
1 | XC6220A331MR-G | XC6220A331MR-G | SOT95P280X120-5N | IC4 | LDO Voltage Regulators |  |  |  |  |  |  |  | LDO Voltage Regulators |  |  | 1.2mm |  | Torex | XC6220A331MR-G |  |  | 865-XC6220A331MR-G | https://www.mouser.co.uk/ProductDetail/Torex-Semiconductor/XC6220A331MR-G?qs=AsjdqWjXhJ8ZSWznL1J0gg%3D%3D

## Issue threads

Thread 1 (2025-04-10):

[README] README incomplet

alexabucur, 2025-04-10:
Ar trebui adaugata o sectiune despre erori, si modul in care au fost tratate/acceptate.

anamariapotoceanu, 2025-04-15:
Am adaugat sectiunea de erori in readme in care am explicat de ce au fost acceptate acestea.

Closed 2025-04-15.

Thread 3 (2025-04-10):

[PCB] Dimensiuni trasee

alexabucur, 2025-04-10:
Toate traseele (nu doar cele de putere) sunt rutate cu acelasi width=0.3mm

anamariapotoceanu, 2025-04-14:
Am făcut o regulă pentru traseele de putere să se ruteze pe width=0.3 mm, iar pentru celelalte am creat o regulă pentru width=0.15 mm.

Closed 2025-04-14.

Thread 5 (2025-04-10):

[PCB] Design Silkscreen

alexabucur, 2025-04-10:
In anumite zone silkscreen-ul este "aglomerat" si nu se pot distinge denumirile componentelor

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

anamariapotoceanu, 2025-04-14:
Am făcut scrisul mai mic (change size) și am așezat pentru fiecare componentă în parte denumirea în dreptul ei.

Closed 2025-04-14.

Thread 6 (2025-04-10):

[PCB] Nume pentru test pads

alexabucur, 2025-04-10:
Test pad-urile trebuie marcate in silkscreen cu numele semnalelor aferente (ex GND, MISO, MOSI etc.)

anamariapotoceanu, 2025-04-15:
Am modificat numele pentru test pad-uri.

Closed 2025-04-15.

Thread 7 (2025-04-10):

[3D] Amplasarea in 3D Design

alexabucur, 2025-04-10:
In fisierul 3D se observa o suprapunere a butonului peste pad-urile rezistentelor; rezistentele ar trebui mutate putin mai departe de buton

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

anamariapotoceanu, 2025-04-14:
Am mutat la dreapta, respectiv la stânga rezistențele și condensatoarele pentru a evita suprapunerea.

Closed 2025-04-14.

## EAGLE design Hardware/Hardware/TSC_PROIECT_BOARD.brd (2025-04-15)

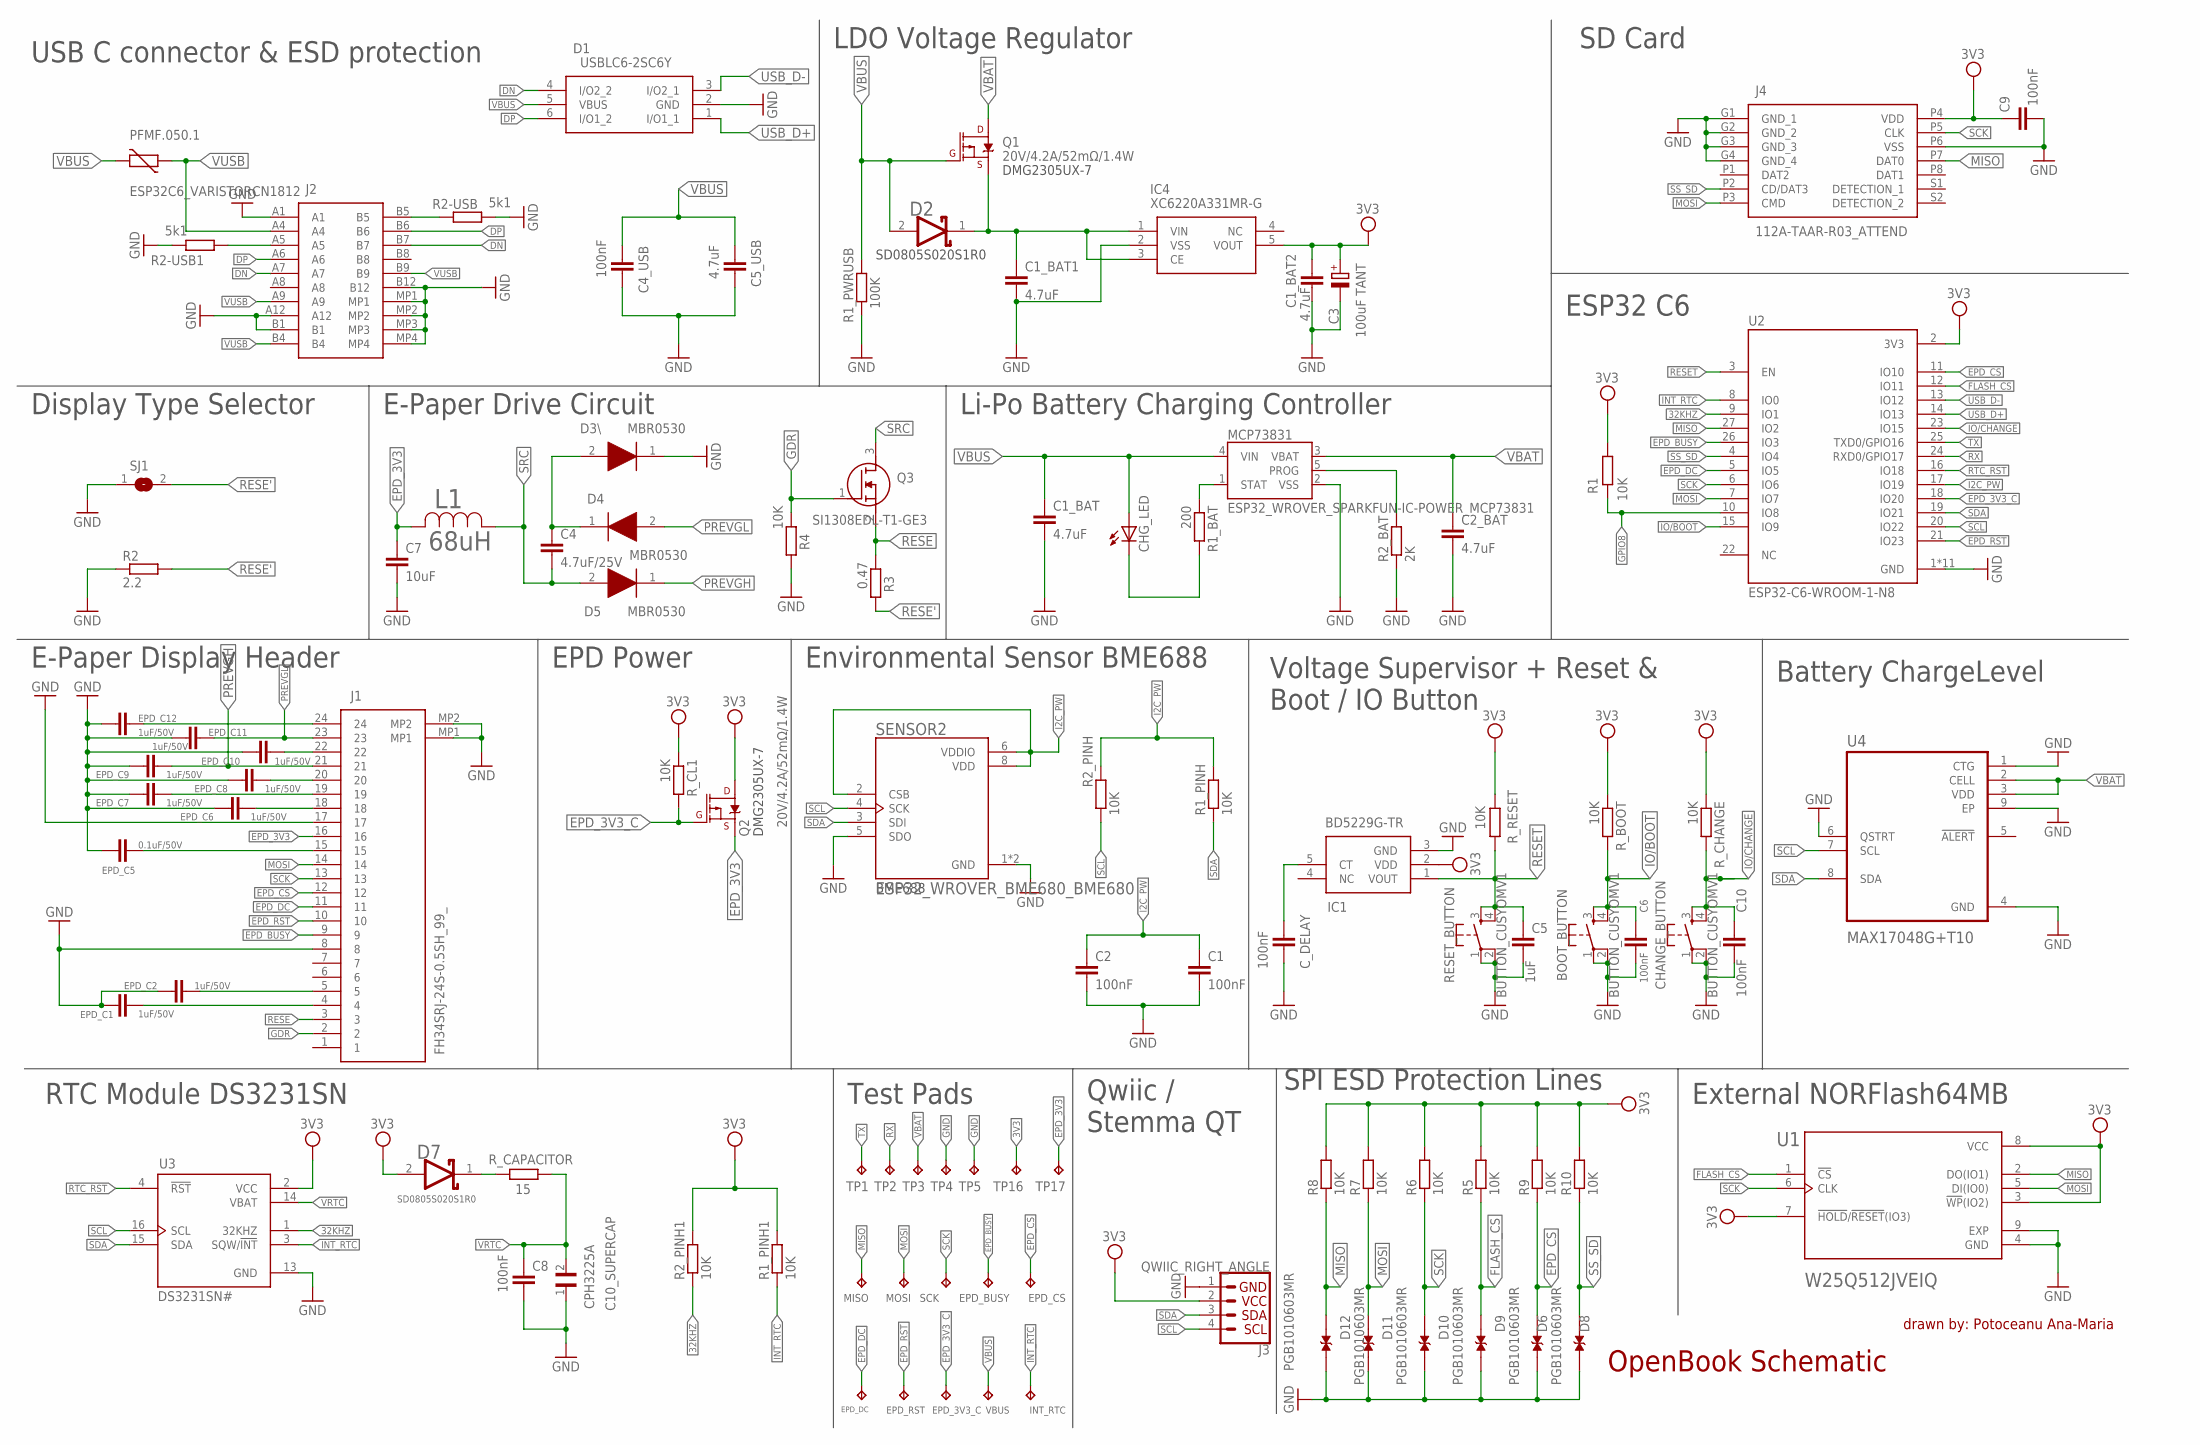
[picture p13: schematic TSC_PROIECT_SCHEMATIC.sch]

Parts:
BOOT_BUTTON: BUTTON_CUSYOMV1; MYBUTTON
C1, C2, C4_USB, C6, C8, C9, C10: 100nF; ESP32_WROVER_EAGLE-LTSPICE_C0402
C1_BAT, C1_BAT1, C1_BAT2, C2_BAT, C5_USB: 4.7uF; ESP32_WROVER_EAGLE-LTSPICE_C0402
C3: 100uF TANT; RCL_CT3528
C4: 4.7uF/25V; ESP32_WROVER_EAGLE-LTSPICE_C0402
C5: 1uF; ESP32_WROVER_EAGLE-LTSPICE_C0402
C7: 10uF; ESP32_WROVER_EAGLE-LTSPICE_C0402
C10_SUPERCAP: CPH3225A; CAPCP3225X100N
CHANGE_BUTTON: BUTTON_CUSYOMV1; MYBUTTON
CHG_LED: ADAFRUIT_LEDCHIP-LED0603; ADAFRUIT_CHIP-LED0603
C_DELAY: 100nF; ESP32_WROVER_EAGLE-LTSPICE_C0402
D1: USBLC6-2SC6Y; SOT95P280X145-6N
D2, D7: ESP32_WROVER_AVX---SD0805S020S1R0_AVX_SD0805S020S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; ESP32_WROVER_AVX---SD0805S020S1R0_AVX_SD0805S020S1R0_0
D3\, D4, D5: MBR0530; SOD3716X135N
D6, D8, D9, D10, D11, D12: PGB1010603MR; DIOC1608X36N
EPD_3V3_C: TPTP20R; TP20R
EPD_BUSY: TPTP20R; TP20R
EPD_C1, EPD_C2, EPD_C6, EPD_C7, EPD_C8, EPD_C9, EPD_C10, EPD_C11, EPD_C12: 1uF/50V; ESP32_WROVER_EAGLE-LTSPICE_C0402
EPD_C5: 0.1uF/50V; ESP32_WROVER_EAGLE-LTSPICE_C0402
EPD_CS: TPTP20R; TP20R
EPD_DC: TPTP20R; TP20R
EPD_RST: TPTP20R; TP20R
IC1: BD5229G-TR; SOT95P280X125-5N
IC4: XC6220A331MR-G; SOT95P280X120-5N
INT_RTC: TPTP20R; TP20R
J1: FH34SRJ-24S-0.5SH_99_; FH34SRJ24S05SH99
J2: SAMACSYS_PARTS_USB4110-GF-A; SAMACSYS_PARTS_USB4110GFA
J3: QWIIC_RIGHT_ANGLE; JST04_1MM_RA
J4: 112A-TAAR-R03_ATTEND; 112ATAARR03ATTEND
L1: 68uH; IND_4828-WE-TPC_WRE
MCP73831: ESP32_WROVER_SPARKFUN-IC-POWER_MCP73831; ESP32_WROVER_SPARKFUN-IC-POWER_SOT23-5
MISO: TPTP20R; TP20R
MOSI: TPTP20R; TP20R
PFMF.050.1: ESP32C6_VARISTORCN1812; ESP32C6_VARISTOR_CT/CN1812
Q1, Q2: 20V/4.2A/52mΩ/1.4W; ESP32_WROVER_SPARKFUN-DISCRETESEMI_SOT23-3
Q3: SI1308EDL-T1-GE3; SOT65P210X110-3N
R1, R1_PINH, R1_PINH1, R2_PINH, R2_PINH1, R4, R5, R6, R7, R8, R9, R10: 10K; ESP32_WROVER_EAGLE-LTSPICE_R0402
R1_BAT: 200; ESP32_WROVER_EAGLE-LTSPICE_R0402
R1_PWRUSB: 100K; ESP32_WROVER_EAGLE-LTSPICE_R0402
R2: 2.2; ESP32_WROVER_EAGLE-LTSPICE_R0402
R2-USB, R2-USB1: 5k1; ESP32_WROVER_EAGLE-LTSPICE_R0402
R2_BAT: 2K; ESP32_WROVER_EAGLE-LTSPICE_R0402
R3: 0.47; ESP32_WROVER_EAGLE-LTSPICE_R0402
RESET_BUTTON: BUTTON_CUSYOMV1; MYBUTTON
R_BOOT: 10K; ESP32_WROVER_EAGLE-LTSPICE_R0402
R_CAPACITOR: 15; ESP32_WROVER_EAGLE-LTSPICE_R0402
R_CHANGE: 10K; ESP32_WROVER_EAGLE-LTSPICE_R0402
R_CL1: 10K; ESP32_WROVER_EAGLE-LTSPICE_R0402
R_RESET: 10K; ESP32_WROVER_EAGLE-LTSPICE_R0402
SCK: TPTP20R; TP20R
SENSOR2: ESP32_WROVER_BME680_BME680; ESP32_WROVER_BME680_PSON80P300X300X100-8N
SJ1: SJ
TP1, TP2, TP3, TP4, TP5, TP16, TP17: TPTP20R; TP20R
U1: W25Q512JVEIQ; SON127P600X800X80-9N
U2: ESP32-C6-WROOM-1-N8; XCVR_ESP32-C6-WROOM-1-N8
U3: DS3231SN#; SOIC127P1032X265-16N
U4: MAX17048G+T10; SON50P200X200X80-9N
VBUS: TPTP20R; TP20R

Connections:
3V3: C1_BAT2.1, C3.+, C9.1, D7.2 (ANODE), IC1.2 (VDD), IC4.5 (VOUT), J3.2, J4.P4 (VDD), Q2.3 (D), R1.1, R1_PINH1.2, R2_PINH1.2, R5.2, R6.2, R7.2, R8.2, R9.2, R10.2, R_BOOT.1, R_CHANGE.1, R_CL1.1, R_RESET.1, TP16.TP, U1.3 (!WP!(IO2)), U1.7 (!HOLD!/!RESET!(IO3)), U1.8 (VCC), U2.2 (3V3), U3.2 (VCC)
32KHZ: R2_PINH1.1, U2.9 (IO1), U3.1 (32KHZ)
DN: D1.4 (I/O2_2), J2.A7, J2.B7
DP: D1.6 (I/O1_2), J2.A6, J2.B6
EPD_3V3: C7.1, J1.16, L1.2, Q2.2 (S), TP17.TP
EPD_3V3_C: EPD_3V3_C.TP, Q2.1 (G), R_CL1.2, U2.18 (IO20)
EPD_BUSY: EPD_BUSY.TP, J1.9, U2.26 (IO3)
EPD_CS: D6.1, EPD_CS.TP, J1.12, R9.1, U2.11 (IO10)
EPD_DC: EPD_DC.TP, J1.11, U2.5 (IO5)
EPD_RST: EPD_RST.TP, J1.10, U2.21 (IO23)
FLASH_CS: D9.1, R5.1, U1.1 (!CS), U2.12 (IO11)
GDR: J1.2, Q3.1 (G), R4.1
GND: BOOT_BUTTON.1, BOOT_BUTTON.2, C1.2, C1_BAT.2, C1_BAT1.2, C1_BAT2.2, C2.2, C2_BAT.2, C3.-, C4_USB.2, C5.2, C5_USB.2, C6.2, C7.2, C8.2, C9.2, C10.2, C10_SUPERCAP.1, CHANGE_BUTTON.1, CHANGE_BUTTON.2, C_DELAY.2, D1.2 (GND), D3\.1 (K), D6.2, D8.2, D9.2, D10.2, D11.2, D12.2, EPD_C1.2, EPD_C2.2, EPD_C5.2, EPD_C6.2, EPD_C7.2, EPD_C8.2, EPD_C9.2, EPD_C10.2, EPD_C11.2, EPD_C12.2, IC1.3 (GND), IC4.2 (VSS), J1.8, J1.17, J1.MP1, J1.MP2, J2.A1, J2.A12, J2.B1, J2.B12, J2.MP1, J2.MP2, J2.MP3, J2.MP4, J3.1, J4.G1 (GND_1), J4.G2 (GND_2), J4.G3 (GND_3), J4.G4 (GND_4), J4.P6 (VSS), MCP73831.2 (VSS), R1_PWRUSB.1, R2.1, R2-USB.2, R2-USB1.1, R2_BAT.1, R4.2, RESET_BUTTON.1, RESET_BUTTON.2, SENSOR2.1 (GND), SENSOR2.5 (SDO), SENSOR2.7 (GND), SJ1.1, TP4.TP, TP5.TP, U1.4 (GND), U1.9 (EXP), U2.1 (GND), U2.28 (GND), U2.29_1 (GND), U2.29_2 (GND), U2.29_3 (GND), U2.29_4 (GND), U2.29_5 (GND), U2.29_6 (GND), U2.29_7 (GND), U2.29_8 (GND), U2.29_9 (GND), U3.13 (GND), U4.1 (CTG), U4.4 (GND), U4.6 (QSTRT), U4.9 (EP)
GPIO8: R1.2, U2.10 (IO8)
I2C_PW: C1.1, C2.1, R1_PINH.2, R2_PINH.2, SENSOR2.2 (CSB), SENSOR2.6 (VDDIO), SENSOR2.8 (VDD), U2.17 (IO19)
INT_RTC: INT_RTC.TP, R1_PINH1.1, U2.8 (IO0), U3.3 (SQW/!INT)
IO/BOOT: BOOT_BUTTON.3, BOOT_BUTTON.4, C6.1, R_BOOT.2, U2.15 (IO9)
IO/CHANGE: C10.1, CHANGE_BUTTON.3, CHANGE_BUTTON.4, R_CHANGE.2, U2.23 (IO15)
MISO: D12.1, J4.P7 (DAT0), MISO.TP, R8.1, U1.2 (DO(IO1)), U2.27 (IO2)
MOSI: D11.1, J1.14, J4.P3 (CMD), MOSI.TP, R7.1, U1.5 (DI(IO0)), U2.7 (IO7)
unnamed: J2.B5, R2-USB.1
unnamed: J2.A5, R2-USB1.2
unnamed: C1_BAT1.1, D2.1 (CATHODE), IC4.1 (VIN), IC4.3 (CE), Q1.2 (S)
unnamed: C4.1, D3\.2 (A), D4.1 (K)
unnamed: EPD_C10.1, J1.22
unnamed: EPD_C5.1, J1.15
unnamed: CHG_LED.C, R1_BAT.2
unnamed: MCP73831.1 (STAT), R1_BAT.1
unnamed: EPD_C8.1, J1.20
unnamed: MCP73831.5 (PROG), R2_BAT.2
unnamed: EPD_C2.1, J1.5
unnamed: D7.1 (CATHODE), R_CAPACITOR.2
unnamed: C_DELAY.1, IC1.5 (CT)
unnamed: EPD_C12.1, J1.24
unnamed: EPD_C7.1, J1.19
unnamed: EPD_C1.1, J1.4
unnamed: EPD_C6.1, J1.18
PREVGH: D5.1 (K), EPD_C9.1, J1.21
PREVGL: D4.2 (A), EPD_C11.1, J1.23
RESE: J1.3, Q3.2 (S), R3.1
RESE': R2.2, R3.2, SJ1.2
RESET: C5.1, IC1.1 (VOUT), RESET_BUTTON.3, RESET_BUTTON.4, R_RESET.2, U2.3 (EN)
RTC_RST: U2.16 (IO18), U3.4 (!RST)
RX: TP2.TP, U2.24 (RXD0/GPIO17)
SCK: D10.1, J1.13, J4.P5 (CLK), R6.1, SCK.TP, U1.6 (CLK), U2.6 (IO6)
SCL: J3.4, R2_PINH.1, SENSOR2.4 (SCK), U2.20 (IO22), U3.16 (SCL), U4.7 (SCL)
SDA: J3.3, R1_PINH.1, SENSOR2.3 (SDI), U2.19 (IO21), U3.15 (SDA), U4.8 (SDA)
SRC: C4.2, D5.2 (A), L1.1, Q3.3 (D)
SS_SD: D8.1, J4.P2 (CD/DAT3), R10.1, U2.4 (IO4)
TX: TP1.TP, U2.25 (TXD0/GPIO16)
USB_D+: D1.1 (I/O1_1), U2.14 (IO13)
USB_D-: D1.3 (I/O2_1), U2.13 (IO12)
VBAT: C2_BAT.1, MCP73831.3 (VBAT), Q1.3 (D), TP3.TP, U4.2 (CELL), U4.3 (VDD)
VBUS: C1_BAT.1, C4_USB.1, C5_USB.1, CHG_LED.A, D1.5 (VBUS), D2.2 (ANODE), MCP73831.4 (VIN), PFMF.050.1.2, Q1.1 (G), R1_PWRUSB.2, VBUS.TP
VRTC: C8.1, C10_SUPERCAP.2, R_CAPACITOR.1, U3.14 (VBAT)
VUSB: J2.A4, J2.A9, J2.B4, J2.B9, PFMF.050.1.1

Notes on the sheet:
SD0805S020S1R0
DMG2305UX-7
BME688
USB C connector & ESD protection
LDO Voltage Regulator
SD Card
Display Type Selector
E-Paper Drive Circuit
Li-Po Battery Charging Controller
ESP32 C6
E-Paper Display Header
EPD Power
Environmental Sensor BME688
Voltage Supervisor + Reset & Boot / IO Button
Battery ChargeLevel
RTC Module DS3231SN
Test Pads
Qwiic / Stemma QT
SPI ESD Protection Lines
External NORFlash64MB
drawn by: Potoceanu Ana-Maria
OpenBook Schematic

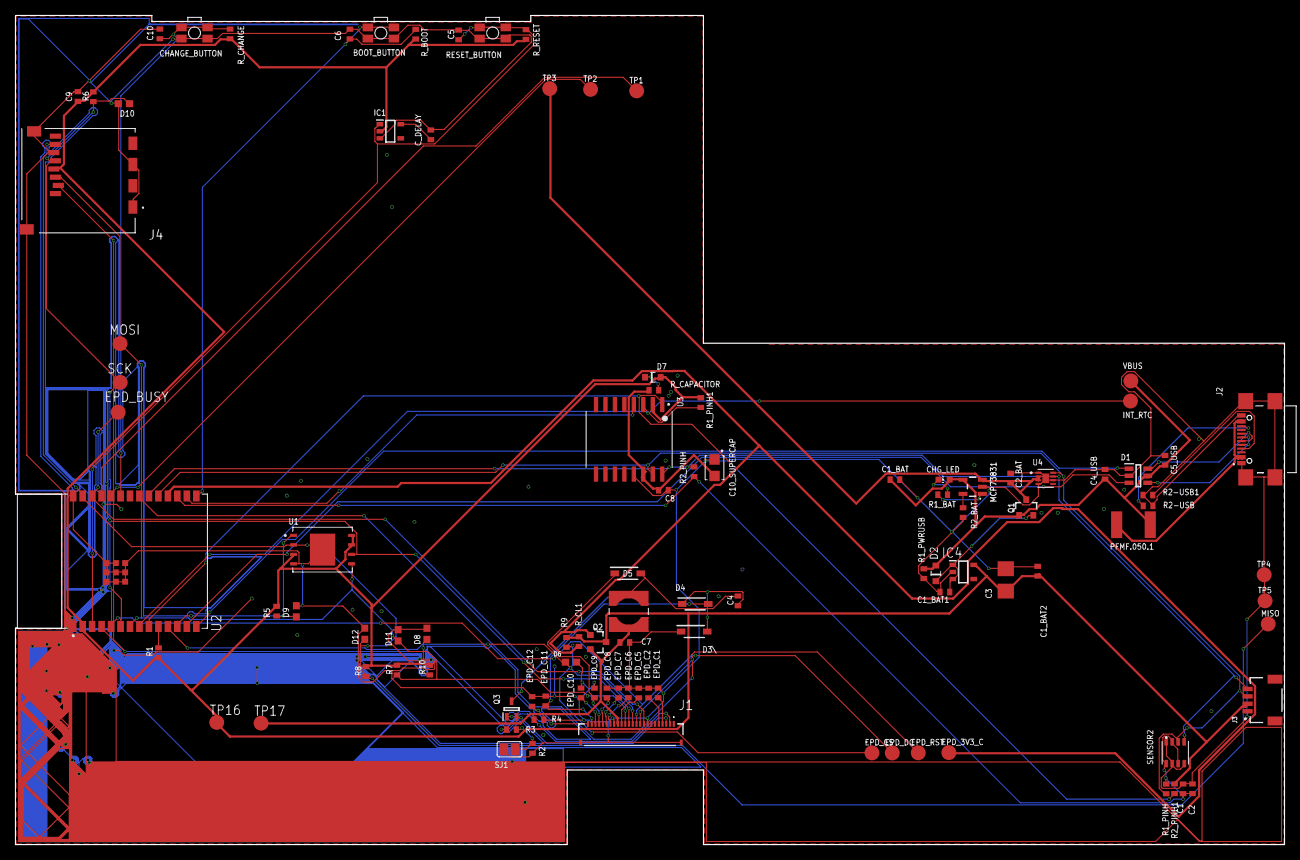
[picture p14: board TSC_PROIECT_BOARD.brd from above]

Board: 2 copper layers, 170.2 x 111.2 mm, 103 parts (0 on the bottom side), 56 nets.

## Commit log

2025-04-06 Add files via upload
    Am adaugat in folderul Hardware, schematicul si boardul din Fusion, carora le-am dat Export.
    [TSC_PROIECT_BOARD.brd, TSC_PROIECT_SCHEMATIC.sch]
2025-04-06 Add files via upload
    Am adaugat folderul Manufacturing care contine gerbers.zip, Bill_of_Materials si Pick_and_Place.csv
    [Bill_of_Materials.csv, Pick_and_Place.csv]
2025-04-06 Add files via upload
    Am adaugat fisierul 3D cu dispozitivul complet (PCB + baterie + display + carcasa) si fisierul 3D Fusion360 cu dispozitivul complet.
2025-04-06 Add files via upload
    Am adaugat fisierul 3D cu dispozitivul complet (PCB + baterie + display + carcasa) (.step) si fisierul 3D Fusion360 cu dispozitivul complet(.f3z)
2025-04-15 Update .brd and .sch
    [TSC_PROIECT_BOARD.brd, TSC_PROIECT_SCHEMATIC.sch]

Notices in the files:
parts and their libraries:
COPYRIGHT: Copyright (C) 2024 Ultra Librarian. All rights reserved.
